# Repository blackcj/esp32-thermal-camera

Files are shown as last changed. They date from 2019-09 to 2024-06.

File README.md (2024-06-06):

# ESP32 Thermal Camera

[MLX90640 thermal camera](https://www.sparkfun.com/products/14844) connected to a [SparkFun Thing Plus - ESP32 WROOM](https://www.sparkfun.com/products/14689)

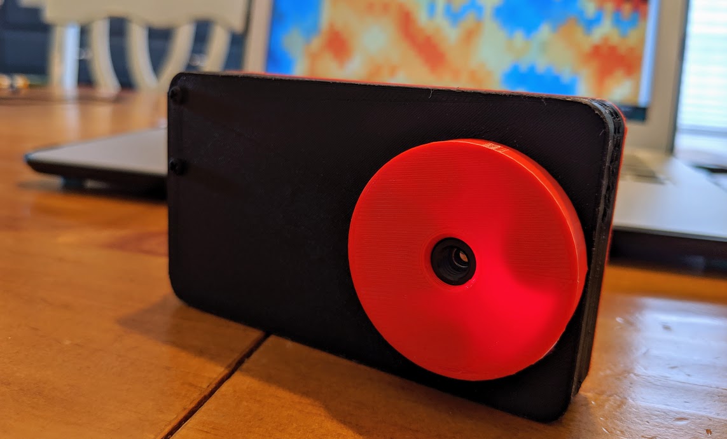
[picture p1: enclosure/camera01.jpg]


## Components

- https://www.sparkfun.com/products/14689
- https://www.sparkfun.com/products/14844 or https://www.sparkfun.com/products/14843
- https://www.sparkfun.com/products/14427 x 2
- https://www.sparkfun.com/products/14532 (Optional)

**Total Cost: ~$115**

> NOTE: You'll also need a micro usb cable to power (and flash) the ESP32. I'm making the assumption that most people have one of these. If you want to make the project portable, you'll also need a battery bank.
 


## Mac Drivers

If using a Mac, you will need to install the following [drivers](https://www.silabs.com/products/development-tools/software/usb-to-uart-bridge-vcp-drivers) to flash the ESP32. More information can be found [here](https://github.com/espressif/arduino-esp32/issues/1084).

## Setup

1. Create an `env.h` file in the IRCameraWiFiServer folder and add your WiFi credentials
   ```
   static const char* wifi_ssid = "YOUR_WIFI_SSID";
   static const char* wifi_pw = "YOU_WIFI_PW";
   ```
2. Connect your SparkFun Thing Plus - ESP32 WROOM using this [guide](https://learn.sparkfun.com/tutorials/esp32-thing-plus-hookup-guide) 
3. Make sure to select **Adafruit ESP32 Feather** in the Arduino IDE
4. Install the following libraries
   - SparkFun_Micro_OLED_Breakout
   - WebSocketsServer
5. Flash the code on your device
6. Navigate to the IP address from the serial monitor

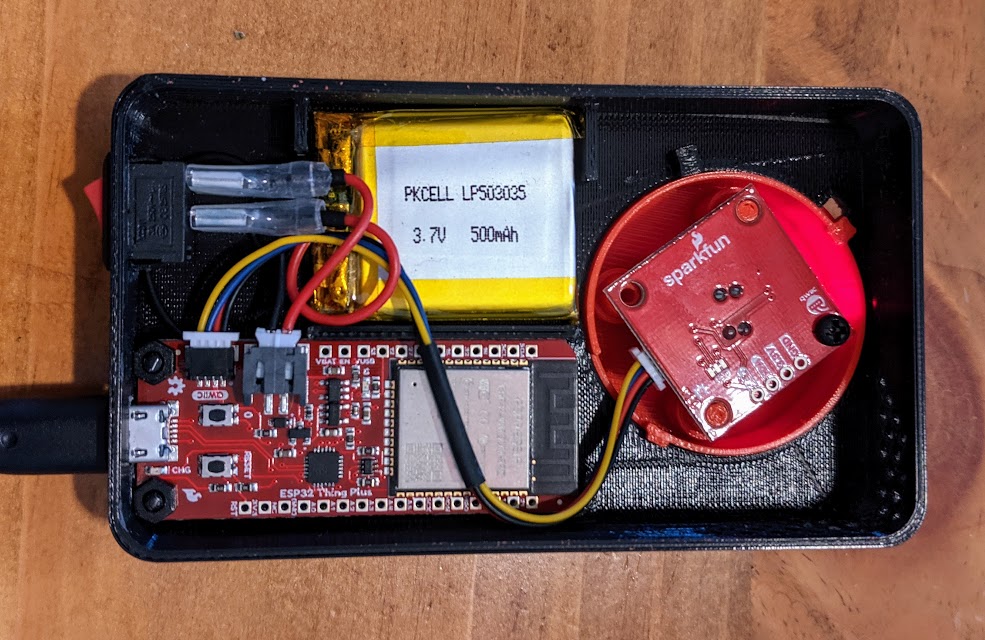
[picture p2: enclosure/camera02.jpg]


### Notes

In retrospect, the power switch should put the device into a low power mode instead of disconnecting the battery. Keeping the battery connected would allow for charging while the device is 'off'. Right now, it must be turned on to charge the battery.

Additional screw mounts for the enclosure would help to ensure the back stays on. Right now it's easy for the back panel to pop off.

There should be enough room for a micro OLED or LCD panel. 3D printing a support layer would help keep the battery in place and provice something to mount the screen to.

## Message Queue

When using both cores of the ESP32, a message queue must be used to send data between the cores. Sharing variables in the global scope will lead to memory issues and will cause problems.

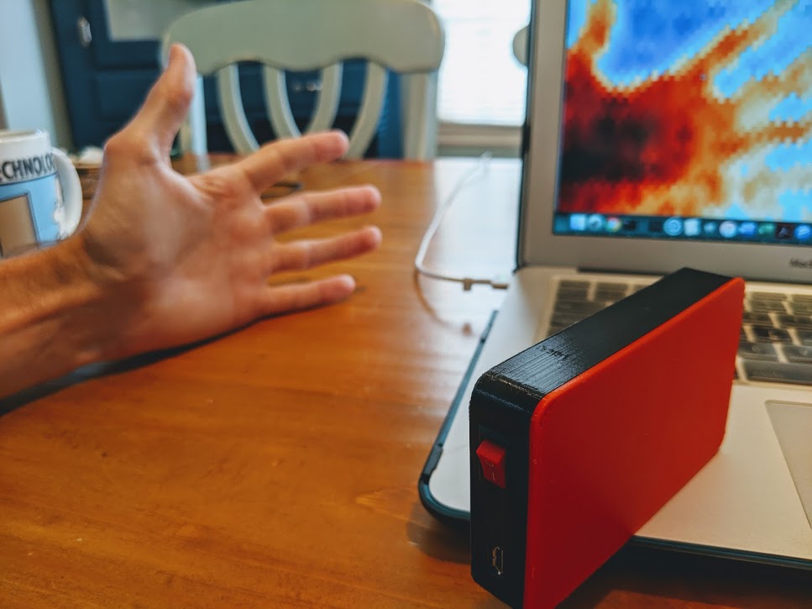
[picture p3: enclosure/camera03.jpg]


## Resources

- https://github.com/melexis/mlx90640-library
- https://github.com/sparkfun/SparkFun_MLX90640_Arduino_Example
- http://minifycode.com/html-minifier/
- https://techtutorialsx.com/2017/11/01/esp32-arduino-websocket-client/
- http://www.iotsharing.com/2017/06/arduino-esp32-freertos-how-to-use-message-queue.html
- http://www.iotsharing.com/2017/05/how-to-turn-esp32-into-web-server.html
- http://www.iotsharing.com/2017/06/arduino-esp32-freertos-how-to-use-task-param-task-priority-task-handle.html
- https://medium.com/@mudassar.tamboli/esp32-ov7670-websocket-video-camera-26c35aedcc64

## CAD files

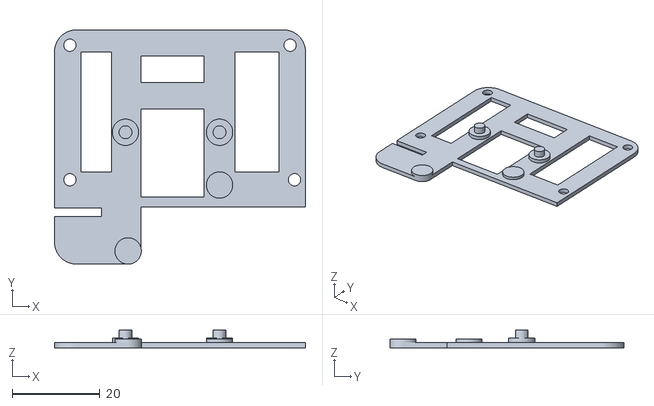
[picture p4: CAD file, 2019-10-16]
enclosure/support.stl
57.1 x 53.3 x 4.00

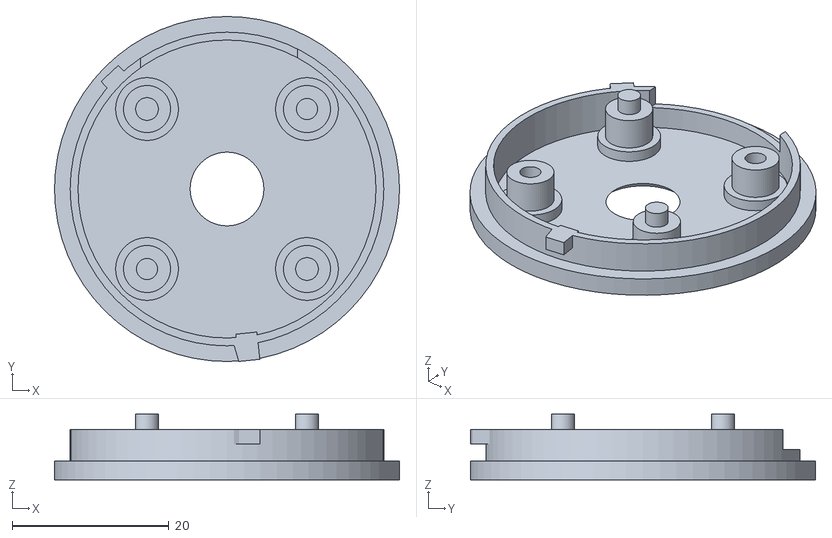
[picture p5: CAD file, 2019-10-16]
enclosure/lens_short.stl
44.0 x 44.0 x 8.40

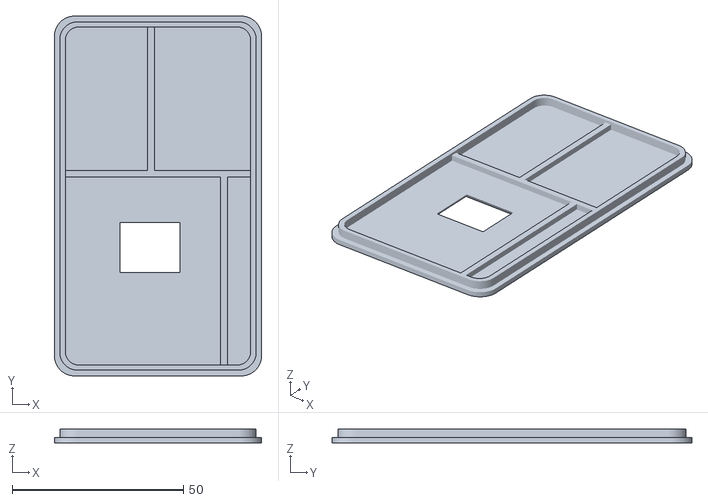
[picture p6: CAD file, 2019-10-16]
enclosure/lid.stl
60.5 x 105.0 x 4.20

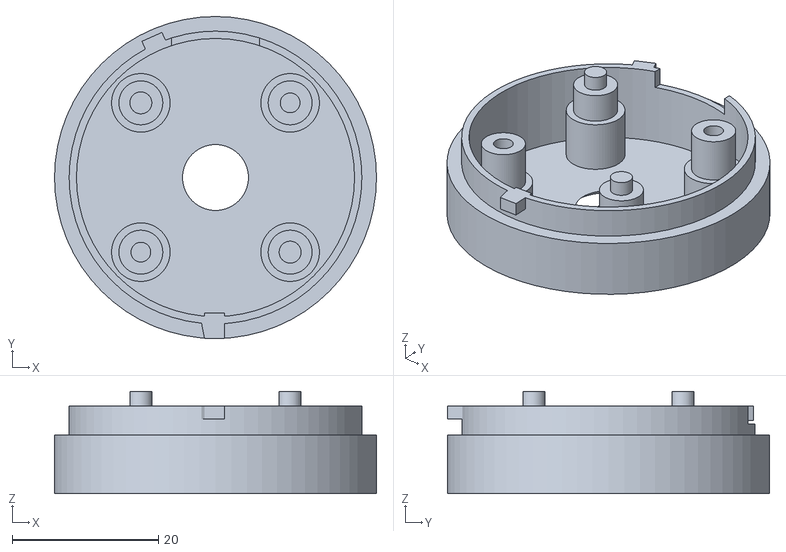
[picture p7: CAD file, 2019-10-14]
enclosure/lens.stl
44.0 x 44.0 x 14.0

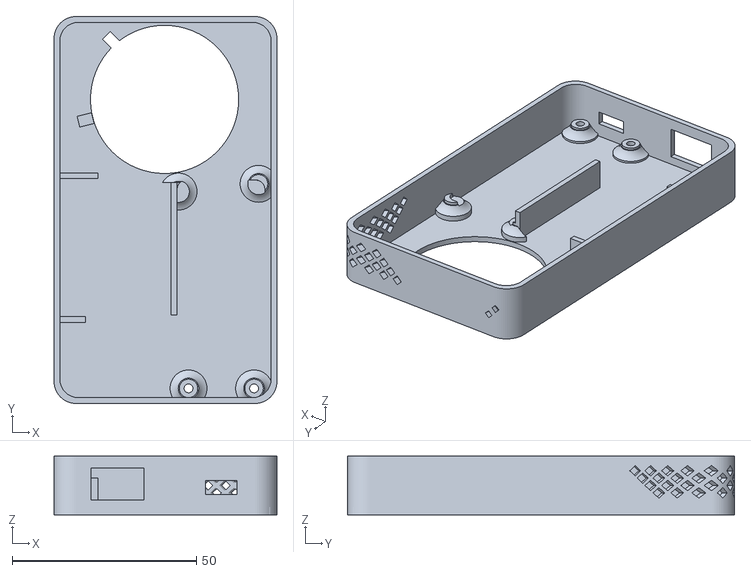
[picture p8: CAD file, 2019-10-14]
enclosure/base.stl
60.5 x 105.0 x 16.0

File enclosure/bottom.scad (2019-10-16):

// Global config variables
enclosure_height = 16;
enclosure_length = 105; // Note: 105mm was a bit too small. Recommend going to 110mm at some point.
enclosure_width = 60.5;
enclosure_radius = 40;
wall_thickness = 1.6;
$fn = 64; // curved resolution (used for cylinders and spheres)

//enclosureBase();

//#displayInternalParts();

//internalSupport();

translate([9,-50,0]) {
    //lensRound(0.4);
    //lensRound(6);
}

translate([-enclosure_width - 10,0,0]) {
    difference() {
        enclosureLid();
        translate([19.3,30.3,-2]) {
            cube([17.4, 14.4, 5]);
        }
        translate([29.4,37.5,-0.1]) {
            rotate([0,0,45])cylinder(8,12,4,$fn=4);
        }
        translate([26.4,37.5,-0.1]) {
            rotate([0,0,45])cylinder(8,12,4,$fn=4);
        }

    }
}

module internalSupport() {
    support_padding = wall_thickness + 0.1;
    support_offset = 50;
    support_length = enclosure_length - support_offset - support_padding;
    support_width = enclosure_width - support_padding * 2;
    
    translate([enclosure_width / 2 - 12.4,support_offset + 30,9]) {
        cylinder(r=3, h=2.2);
        cylinder(r=1.47, h=4);
    }
    translate([enclosure_width / 2 + 9,support_offset + 30,9]) {
        cylinder(r=3, h=2.2);
        cylinder(r=1.47, h=4);
    }
    translate([enclosure_width / 2 - 11.8,support_offset + 3,9]) {
        cylinder(r=3, h=2);
    }
    translate([enclosure_width / 2 + 9,support_offset + 18,9]) {
        cylinder(r=3, h=2);
    }
    
    difference() {
        translate([support_padding,support_offset,9]) {
            difference() {
                rcube([support_width, support_length,1.2], 5);
                translate([6,21,-2]) {
                    cube([7, support_length - 26, 5]);
                }
                translate([support_width - 16,21,-2]) {
                    cube([10, support_length - 26, 5]);
                }
                translate([support_width / 2 - support_width / 8 - 1.7,support_length - 38,-2]) {
                    cube([support_width / 4, 20, 5]);
                }
                translate([support_width / 2 - support_width / 8 - 1.7,support_length - 12,-2]) {
                    cube([support_width / 4, 6, 5]);
                }
                translate([support_width / 2 - support_width / 8 - 1.7,-1,-2]) {
                    cube([support_width, 14, 5]);
                }
                translate([support_width / 2 - support_width / 8 - 5,-1,-2]) {
                    cube([support_width, 4, 5]);
                }
            }
        }
        translate([3.5 + support_padding,enclosure_length - 3.5 - support_padding,6]) {
            cylinder(r=1.4, h=(10 - support_padding));
        }
        translate([enclosure_width - 3.5 - support_padding,enclosure_length - 3.5 - support_padding,6]) {
            cylinder(r=1.4, h=(10 - support_padding));
        }
        translate([enclosure_width - 2.5 - support_padding,support_offset + 17.5 + support_padding,6]) {
            cylinder(r=1.4, h=(10 - support_padding));
        }
        translate([3.5 + support_padding,support_offset + 17.5 + support_padding,6]) {
            cylinder(r=1.4, h=(10 - support_padding));
        }
        translate([0,60.8,6]) {
            cube([12.4, 2, 12]);
        }
    }
}

module displayInternalParts() {
    // Power switch
    translate([10,-1.2,4])cube([14.2,12,8.8]);
    translate([12,-3.4,5])rotate([0,0,20])cube([10,3,7]);
    translate([13,10,6])cube([1.2,6,4]);
    translate([20,10,6])cube([1.2,6,4]);
    
    // Battery
    translate([2,24,2]) {
        // 500 mAh
        cube([29,36,6]);
        // 400 mAh
        //#cube([26,37,5]);
    }

    // Feather board
    translate([enclosure_width - 27,wall_thickness,5]) {
        thingPlusBoard();
    }
    
    // OLED
    
}

module enclosureLid() {
    lid_offset = wall_thickness + 0.1;
    rcube([enclosure_width,enclosure_length,wall_thickness], 6);
    translate([wall_thickness,58,lid_offset - 0.1])cube([enclosure_width - wall_thickness * 2, 2, 1.8]);
    translate([enclosure_width/2 - 3,58,lid_offset - 0.1])cube([2, 44, 1.8]);
    translate([enclosure_width - 12,lid_offset,lid_offset - 0.1])cube([2, 58, 1.8]);
    difference() {
        
        // Make the cylinder hollow
        translate([wall_thickness,lid_offset,lid_offset - 0.1]) {
            rcube([enclosure_width - wall_thickness * 2, enclosure_length - lid_offset * 2,2.6], 5.2);
          inner_height = enclosure_height;
          inner_radius = enclosure_radius - (lid_offset * 2);
        }
        translate([wall_thickness*2,wall_thickness*2,1]) {
            rcube([enclosure_width - wall_thickness * 4, enclosure_length - wall_thickness * 4,6], 4);
          inner_height = enclosure_height;
          inner_radius = enclosure_radius - (wall_thickness * 2);
        }
    }
}

module enclosureBase() {
    difference() {
        enclosureWalls();
        // Micro usb slot
        translate([enclosure_width - 19.4,-1,5.7])cube([8.8,4,3.8]);
        // Power switch
        translate([10,-1,4])cube([14.2,8,8.8]);
        // Camera lense
        translate([9,enclosure_length - 43.5,-2]) {
            translate([21,21,0]) cylinder(r=40.2/2,h=8);
        }
        // Lens notch
        translate([16,enclosure_length - 9,-1]) {
            rotate([0,0,45]) {
                cube([3,4,3]);
            }
        }
        // Camera strap
        translate([5.4,enclosure_length - 9,8]) {
            rotate([10,45,15]) {
                cube([1.6,20,1.6]);
            }
        }
        translate([4.8,enclosure_length - 9.6,6.6]) {
            rotate([0,45,-10]) {
                cube([1.6,20,1.6]);
            }
        }
    }
    
    difference() {
        translate([enclosure_width - 24,4.1,0]) {
            difference() {
                featherScrew();
                translate([-3.1,-2.5,5]) {
                    thingPlusBoard();
                }

            }
        }
        // Battery
        translate([3,24,1]) {
            cube([29,36,6]);
        }
        // Front face
        translate([20,-1.1,-1]) {
            cube([41,wall_thickness+1,enclosure_height + 2]);
        }
    }
}

module rcube(size, radius) {
    // rcube module found here: https://www.prusaprinters.org/parametric-design-in-openscad/
    hull() {
        translate([radius, radius]) cylinder(r = radius, h = size[2]);
        translate([size[0] - radius, radius]) cylinder(r = radius, h = size[2]);
        translate([size[0] - radius, size[1] - radius]) cylinder(r = radius, h = size[2]);
        translate([radius, size[1] - radius]) cylinder(r = radius, h = size[2]);
        //translate([1, size[1] - 1]) cylinder(r = 1, h = size[2]);
    }
}

// Draw exterior walls for the enclosure
module enclosureWalls() {
    translate([7,enclosure_length - 30,1]) {
        rotate([0,0,14]) {
            cube([4,3,3.6]);
        }
    }
    translate([1.6,22,0])cube([7,1.6,10]);
    translate([0,61,0])cube([12,1.6,10]);
    translate([enclosure_width - 28.7,24,0])cube([1.6,36,10]);
    // Cylinder with a smaller cylinder cut out of it
    difference() {
        rcube([enclosure_width,enclosure_length,enclosure_height], 6);

        // Make the cylinder hollow
        translate([wall_thickness,wall_thickness,wall_thickness]) {
            rcube([enclosure_width - wall_thickness * 2, enclosure_length - wall_thickness * 2,enclosure_height], 5);
          inner_height = enclosure_height;
          inner_radius = enclosure_radius - (wall_thickness * 2);
        }
        // Radial vents
        translate([enclosure_width / 2,enclosure_length / 1.5,enclosure_height - 14]) {
          radialVents(2, 7, 2, 3, enclosure_length + 20);
        }
        // Through hole for screw
        translate([enclosure_width - 24,4.1,-2]) {
            cylinder(r=1.2, h=16);
        }
        // Through hole for screw
        translate([enclosure_width - 6.22,4.1,-2]) {
            cylinder(r=1.2, h=16);
        }
    }
}

// Radial vents
// ventSpacing in mm
// horizontalSpacing in degrees (divisible by 360)
module radialVents(verticalSpacing, horizontalSpacing, size, numRows, ventRadius) {
    for ( m = [0 : numRows] ){
        //for ( k = [102 : 130] ){
        for ( k = [94 : 101] ){
            // Rotate by 45 degrees to avoid needing support when printing
            translate([0,0,m * verticalSpacing + 4]) {
                offset = horizontalSpacing / 2;
                rotate( k * horizontalSpacing - m * offset, [0, 0, 1]){
                    rotate( 45, [0, 1, 0]) {
                        cube([size, ventRadius, size]);
                    }
                }
            }
        }
    }
}
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

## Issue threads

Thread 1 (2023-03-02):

MLX90640 not detected at default I2C address

ArshyaL, 2023-03-02:
Hi,

I am getting the following error while compiling the code :

In file included from C:\Users\Arshya\Documents\Arduino\libraries\MLX90640_I2C_Driver\MLX90640_I2C_Driver.cpp:19:0:
C:\Users\Arshya\AppData\Local\Arduino15\packages\esp32\hardware\esp32\1.0.6\libraries\Wire\src/Wire.h: In function 'int MLX90640_I2CRead(uint8_t, unsigned int, unsigned int, uint16_t*)':
C:\Users\Arshya\AppData\Local\Arduino15\packages\esp32\hardware\esp32\1.0.6\libraries\Wire\src/Wire.h:103:13: note: candidate 1: uint8_t TwoWire::requestFrom(int, int)
     uint8_t requestFrom(int address, int size);
             ^
C:\Users\Arshya\AppData\Local\Arduino15\packages\esp32\hardware\esp32\1.0.6\libraries\Wire\src/Wire.h:101:13: note: candidate 2: uint8_t TwoWire::requestFrom(uint8_t, uint8_t)
     uint8_t requestFrom(uint8_t address, uint8_t size);

Yet,  I am able to compile it

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

When I try to upload and run it on serial monitor, I get the following line printed :

MLX90640 not detected at default I2C address. Please check wiring. Freezing

This seems to be from the if statement in the code.

Wire.beginTransmission((uint8_t)MLX90640_address);
    if (Wire.endTransmission() != 0) {
        Serial.println("MLX90640 not detected at default I2C address. Please check wiring. Freezing.");
        while (1);

Any way to resolve this?

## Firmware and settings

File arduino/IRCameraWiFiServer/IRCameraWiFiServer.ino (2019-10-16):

/*
 MLX90640 thermal camera connected to a SparkFun Thing Plus - ESP32 WROOM

 Created by: Christopher Black
 */

#include <WiFi.h>
#include <ESPmDNS.h>
#include <Wire.h>  // Used for I2C communication
#include <SFE_MicroOLED.h>  // Include the SFE_MicroOLED library
#include <WebSocketsServer.h>
#include "MLX90640_API.h"
#include "MLX90640_I2C_Driver.h"
#include "env.h"
#include "webpage.h"

// MicroOLED variables
#define PIN_RESET 9  
#define DC_JUMPER 1 
// MicroOLED oled(PIN_RESET, DC_JUMPER);    // I2C declaration

// WiFi variables
const char* ssid     = wifi_ssid;
const char* password = wifi_pw;
WiFiServer server(80);


//declare socket related variables
WebSocketsServer webSocket = WebSocketsServer(81);

// MLX90640 variables
#define TA_SHIFT -64; // Default shift for MLX90640 in open air is 8
static float mlx90640To[768];

// Used to compress data to the client
char positive[27] = "ABCDEFGHIJKLMNOPQRSTUVWXYZ";
char negative[27] = "abcdefghijklmnopqrstuvwxyz";

TaskHandle_t TaskA;
/* this variable hold queue handle */
xQueueHandle xQueue;

int total = 0;

void setup()
{
    Serial.begin(115200);
    delay(1000);

    Serial.println();
    Serial.println();
    Serial.print("Connecting to ");
    Serial.println(ssid);

    // Connect to the WiFi network
    WiFi.begin(ssid, password);
    WiFi.setHostname("esp32thing1");
    int retry = 0;
    while (WiFi.status() != WL_CONNECTED) {
        delay(1000);
        retry += 1;
        Serial.print(".");
        if (retry > 4 ) {
          // Retry after 5 seconds
          Serial.println("");
          WiFi.begin(ssid, password);
          retry = 0;
        }
    }

    Serial.println("");
    Serial.println("WiFi connected.");
    Serial.println("IP address: ");
    Serial.println(WiFi.localIP());

    if (!MDNS.begin("thermal")) {
        Serial.println("Error setting up MDNS responder!");
    } else {
        MDNS.addService("http", "tcp", 80);
        MDNS.addService("ws", "tcp", 81);
        Serial.println("mDNS responder started");
    }
    
    server.begin();
    
    xQueue = xQueueCreate(1, sizeof(mlx90640To));
    xTaskCreatePinnedToCore(
      Task1,                  /* pvTaskCode */
      "Workload1",            /* pcName */
      100000,                   /* usStackDepth */
      NULL,                   /* pvParameters */
      1,                      /* uxPriority */
      &TaskA,                 /* pxCreatedTask */
      0);                     /* xCoreID */
    xTaskCreate(
      receiveTask,           /* Task function. */
      "receiveTask",        /* name of task. */
      10000,                    /* Stack size of task */
      NULL,                     /* parameter of the task */
      1,                        /* priority of the task */
      NULL);                    /* Task handle to keep track of created task */

    webSocket.begin();
    webSocket.onEvent(webSocketEvent);
}

int value = 0;
int dataVal = 0;

void loop(){
  webSocket.loop();
  
  WiFiClient client = server.available();   // listen for incoming clients

  if (client) {
    Serial.println("New Client.");
    String currentLine = "";
    while (client.connected()) {
      if (client.available()) {
        char c = client.read();
        Serial.write(c);
        if (c == '\n') {

          // if the current line is blank, you got two newline characters in a row.
          // that's the end of the client HTTP request, so send a response:
          if (currentLine.length() == 0) {
            // HTTP headers always start with a response code (e.g. HTTP/1.1 200 OK)
            // and a content-type so the client knows what's coming, then a blank line:
            client.println("HTTP/1.1 200 OK");
            client.println("Content-type:text/html");
            client.println();
            client.print("<script>const ipAddress = '"); 
            client.print(WiFi.localIP());
            client.print("'</script>");
            client.println();
            // the content of the HTTP response follows the header:
            client.print(canvas_htm);
            
            // The HTTP response ends with another blank line:
            client.println();
            // break out of the while loop:
            break;
          } else {    // if you got a newline, then clear currentLine:
            currentLine = "";
          }
        } else if (c != '\r') {  // if you got anything else but a carriage return character,
          currentLine += c;      // add it to the end of the currentLine
        }
      }
    }
    // close the connection:
    client.stop();
    Serial.println("Client Disconnected.");
  }
}

// Capture thermal image on a different thread
void Task1( void * parameter )
{
    int tick = 0;
    const byte MLX90640_address = 0x33; //Default 7-bit unshifted address of the MLX90640
    
    MicroOLED oled(PIN_RESET, DC_JUMPER);    // I2C declaration
    Wire.setClock(400000L);
    Wire.begin();
    
    oled.begin();    // Initialize the OLED
    oled.clear(ALL); // Clear the display's internal memory
    //oled.display();  // Display what's in the buffer (splashscreen)
    delay(50);
    oled.clear(PAGE); // Clear the buffer
    oled.print("Welcome!");
    delay(400);
    oled.display(); // Draw on the screen
    paramsMLX90640 mlx90640;
    Wire.beginTransmission((uint8_t)MLX90640_address);
    if (Wire.endTransmission() != 0) {
        Serial.println("MLX90640 not detected at default I2C address. Please check wiring. Freezing.");
        while (1);
    }
    Serial.println("MLX90640 online!");

    //Get device parameters - We only have to do this once
    int status;
    uint16_t eeMLX90640[832];
    status = MLX90640_DumpEE(MLX90640_address, eeMLX90640);

    if (status != 0) {
        Serial.println("Failed to load system parameters");
    }
    status = MLX90640_ExtractParameters(eeMLX90640, &mlx90640);
    if (status != 0) {
        Serial.println("Parameter extraction failed");
    }
    MLX90640_SetRefreshRate(MLX90640_address, 0x05);
    Wire.setClock(1000000L);
    float mlx90640Background[768];
    for( ;; )
    {
//      String startMessage = "Capturing thermal image on core ";
//      startMessage.concat(xPortGetCoreID());
//      Serial.println( startMessage );
//      long startTime = millis();
      for (byte x = 0 ; x < 2 ; x++) //Read both subpages
      {
        uint16_t mlx90640Frame[834];
        int status = MLX90640_GetFrameData(MLX90640_address, mlx90640Frame);
        if (status < 0)
        {
          Serial.print("GetFrame Error: ");
          Serial.println(status);
        }
    
        float vdd = MLX90640_GetVdd(mlx90640Frame, &mlx90640);
        float Ta = MLX90640_GetTa(mlx90640Frame, &mlx90640);
  
        float tr = Ta - TA_SHIFT; //Reflected temperature based on the sensor ambient temperature
        float emissivity = 0.95;
  
        MLX90640_CalculateTo(mlx90640Frame, &mlx90640, emissivity, tr, mlx90640Background);
      }
//      long stopReadTime = millis();
//      Serial.print("Read rate: ");
//      Serial.print( 1000.0 / (stopReadTime - startTime), 2);
//      Serial.println(" Hz");
      tick += 1;
      if (tick > 10) {
        float maxReading = mlx90640To[0];
        float minReading = mlx90640To[0];
        float avgReading = mlx90640To[0];
        for (int x = 0 ; x < 768 ; x++)
        {
          if (isnan(mlx90640To[x])) {
            continue;
          }
          avgReading = (avgReading + mlx90640To[x]) / 2;
          if ( mlx90640To[x] > maxReading) {
            maxReading = mlx90640To[x];
          }
          if ( mlx90640To[x] < minReading) {
            minReading = mlx90640To[x];
          }
        }
        avgReading = avgReading * 1.8 + 32;
        maxReading = maxReading * 1.8 + 32;
        minReading = minReading * 1.8 + 32;
        String output = "Max:";
        output.concat(maxReading);
        String minOutput = "Min:";
        minOutput.concat(minReading);
        String avgOutput = "Avg:";
        avgOutput.concat(avgReading);
        oled.setCursor(0, 0);
        oled.clear(PAGE); // Clear the buffer
        oled.print(output);
        oled.setCursor(0, 10);
        oled.print(minOutput);
        oled.setCursor(0, 20);
        oled.print(avgOutput);
        oled.display(); // Draw on the screen
        tick = 0;
      }
      /* time to block the task until the queue has free space */
      const TickType_t xTicksToWait = pdMS_TO_TICKS(100);
      xQueueSendToFront( xQueue, &mlx90640Background, xTicksToWait );
      
      const TickType_t xDelay = 20 / portTICK_PERIOD_MS; // 8 Hz is 1/8 second
      vTaskDelay(xDelay);
  }
}

void receiveTask( void * parameter )
{
  /* keep the status of receiving data */
  BaseType_t xStatus;
  /* time to block the task until data is available */
  const TickType_t xTicksToWait = pdMS_TO_TICKS(100);
  for(;;){
    /* receive data from the queue */
    xStatus = xQueueReceive( xQueue, &mlx90640To, xTicksToWait );
    /* check whether receiving is ok or not */
    if(xStatus == pdPASS){
      compressAndSend();
      total += 1;
    }
  }
  vTaskDelete( NULL );
}

void webSocketEvent(uint8_t num, WStype_t type, uint8_t * payload, size_t length) {
    
    switch(type) {
        case WStype_DISCONNECTED:
            Serial.println("Socket Disconnected.");
            break;
        case WStype_CONNECTED:
            {
                IPAddress ip = webSocket.remoteIP(num);
                Serial.println("Socket Connected.");
                // send message to client
                webSocket.sendTXT(num, "Connected");
            }
            break;
        case WStype_TEXT:
            // send message to client
            break;
        case WStype_BIN:
        case WStype_ERROR:      
        case WStype_FRAGMENT_TEXT_START:
        case WStype_FRAGMENT_BIN_START:
        case WStype_FRAGMENT:
        case WStype_FRAGMENT_FIN:
            break;
    }
}

// Some precision is lost during compression but data transfer speeds are
// much faster. We're able to get a higher frame rate by compressing data.
void compressAndSend() 
{
    String resultText = "";
    int numDecimals = 1;
    int accuracy = 8;
    int previousValue = round(mlx90640To[0] * pow(10, numDecimals));
    previousValue = previousValue - (previousValue % accuracy);
    resultText.concat(numDecimals);
    resultText.concat(accuracy);
    resultText.concat(previousValue);
    resultText.concat(".");
    char currentLetter = 'A';
    char previousLetter = 'A';
    int letterCount = 1;
    int columnCount = 32;
    
    for (int x = 1 ; x < 768; x += 1)
    {
        int currentValue = round(mlx90640To[x] * pow(10, numDecimals));
        currentValue = currentValue - (currentValue % accuracy);
        if(x % columnCount == 0) {
            previousValue = round(mlx90640To[x - columnCount] * pow(10, numDecimals));
            previousValue = previousValue - (previousValue % accuracy);
        }
        int correction = 0;
        int diffIndex = (int)(currentValue - previousValue);
        if(abs(diffIndex) > 0) {
            diffIndex = diffIndex / accuracy;
        }
        if(diffIndex > 25) {
            //correction = (diffIndex - 25) * accuracy;
            diffIndex = 25;
        } else if(diffIndex < -25) {
            //correction = (diffIndex + 25) * accuracy;
            diffIndex = -25;
        }

        if(diffIndex >= 0) {
            currentLetter = positive[diffIndex];
        } else {
            currentLetter = negative[abs(diffIndex)];
        }
        
        if(x == 1) {
            previousLetter = currentLetter;
        } else if(currentLetter != previousLetter) {
            
            if(letterCount == 1) {
                resultText.concat(previousLetter);
            } else {
                resultText.concat(letterCount);
                resultText.concat(previousLetter);
            }
            previousLetter = currentLetter;
            letterCount = 1;
        } else {
            letterCount += 1;
        }
        
        previousValue = currentValue - correction;
    }
    if(letterCount == 1) {
        resultText.concat(previousLetter);
    } else {
        resultText.concat(letterCount);
        resultText.concat(previousLetter);
    }
    webSocket.broadcastTXT(resultText);
}

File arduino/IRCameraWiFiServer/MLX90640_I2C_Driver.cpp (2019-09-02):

/**
   @copyright (C) 2017 Melexis N.V.

   Licensed under the Apache License, Version 2.0 (the "License");
   you may not use this file except in compliance with the License.
   You may obtain a copy of the License at

       http://www.apache.org/licenses/LICENSE-2.0

   Unless required by applicable law or agreed to in writing, software
   distributed under the License is distributed on an "AS IS" BASIS,
   WITHOUT WARRANTIES OR CONDITIONS OF ANY KIND, either express or implied.
   See the License for the specific language governing permissions and
   limitations under the License.

*/


#include <Wire.h>

#include "MLX90640_I2C_Driver.h"

void MLX90640_I2CInit()
{

}

//Read a number of words from startAddress. Store into Data array.
//Returns 0 if successful, -1 if error
int MLX90640_I2CRead(uint8_t _deviceAddress, unsigned int startAddress, unsigned int nWordsRead, uint16_t *data)
{

  //Caller passes number of 'unsigned ints to read', increase this to 'bytes to read'
  uint16_t bytesRemaining = nWordsRead * 2;

  //It doesn't look like sequential read works. Do we need to re-issue the address command each time?

  uint16_t dataSpot = 0; //Start at beginning of array

  //Setup a series of chunked I2C_BUFFER_LENGTH byte reads
  while (bytesRemaining > 0)
  {
    Wire.beginTransmission(_deviceAddress);
    Wire.write(startAddress >> 8); //MSB
    Wire.write(startAddress & 0xFF); //LSB
    if (Wire.endTransmission(false) != 0) //Do not release bus
    {
      //Serial.println("No ack read");
      return (0); //Sensor did not ACK
    }

    uint16_t numberOfBytesToRead = bytesRemaining;
    if (numberOfBytesToRead > I2C_BUFFER_LENGTH) numberOfBytesToRead = I2C_BUFFER_LENGTH;

    Wire.requestFrom((uint8_t)_deviceAddress, numberOfBytesToRead);
    if (Wire.available())
    {
      for (uint16_t x = 0 ; x < numberOfBytesToRead / 2; x++)
      {
        //Store data into array
        data[dataSpot] = Wire.read() << 8; //MSB
        data[dataSpot] |= Wire.read(); //LSB

        dataSpot++;
      }
    }

    bytesRemaining -= numberOfBytesToRead;

    startAddress += numberOfBytesToRead / 2;
  }

  return (0); //Success
}

//Set I2C Freq, in kHz
//MLX90640_I2CFreqSet(1000) sets frequency to 1MHz
void MLX90640_I2CFreqSet(int freq)
{
  //i2c.frequency(1000 * freq);
  Wire.setClock((long)1000 * freq);
}

//Write two bytes to a two byte address
int MLX90640_I2CWrite(uint8_t _deviceAddress, unsigned int writeAddress, uint16_t data)
{
  Wire.beginTransmission((uint8_t)_deviceAddress);
  Wire.write(writeAddress >> 8); //MSB
  Wire.write(writeAddress & 0xFF); //LSB
  Wire.write(data >> 8); //MSB
  Wire.write(data & 0xFF); //LSB
  if (Wire.endTransmission() != 0)
  {
    //Sensor did not ACK
    //Serial.println("Error: Sensor did not ack");
    return (-1);
  }

  uint16_t dataCheck;
  MLX90640_I2CRead(_deviceAddress, writeAddress, 1, &dataCheck);
  if (dataCheck != data)
  {
    //Serial.println("The write request didn't stick");
    return -2;
  }

  return (0); //Success
}

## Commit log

2019-09-02 Added MLX90640 library. Set up a simple server that displays all readings from the IR sensor when visiting the IP address of the device from a browser.
2019-09-02 Added web socket server. Temporarily removed web interface, this will be added back shortly with socket integration.
    [IRCameraWiFiServer.ino]
2019-09-03 Moved temperature readings and oled display into a task on a different processor core. Using both processor cores significantly increases the performance of the application. Created a webpage to init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
2019-10-13 Added bottom half of the enclosure for the thermal camera.
    [bottom.scad]
2019-10-14 Added STL files for the base, lid and lens. Updated the 3d model to better fit the components.
    [base.stl, bottom.scad, lens.stl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]
2019-10-14 Updated HTML to include an average high temperature. Added a button to flip from forward to backward orientation.
2019-10-14 Temporarily removed OLED code. Updated TA_SHIFT to a number that works within the enclosure.
2019-10-14 Updated enclosure lid and lens to improve fit with the base. Added images for the camera enclosure. Cleaned up the logic for coloring pixels based on data from the camera.
    [bottom.scad, lens.stl, lid.stl]
2019-10-16 Added support structure to hold the micro oled. Updated the readme to include an additional image. Brought back the micro oled code for the micro controller.
    [bottom.scad, lens_short.stl, lid.stl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]
